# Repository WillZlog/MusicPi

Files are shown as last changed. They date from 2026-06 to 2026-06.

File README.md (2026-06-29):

# MusicPi







 


A server + remote that plays music so I don't have to be on my phone or on my computer to listen to music.

It controls playback with no phone, or computer necessary, so you can relax and listen to music **without the temptation of screens**. The case and PCB are all custom designed, by [@WillZlog](https://www.github.com/WillZlog).

## Tech Stack

**Remote:** ESP32 S3, buttons, OLED

**Receiver Dongle:** ESP32-C3 Super Mini, USB A - USB C Cable

**Raspberry Pi:** Python, Serial Listener, Librespot/Spotify

**CAD:** Onshape, custom enclosure

## Features

**Radio Mode:** Streams songs directly from commercial-free internet radio stations like FIP (France Inter Paris) or TSF (Télégraphie Sans Fil), to give you the classic radio style

**Physical Remote:** A physical remote with a (soon toggleable) OLED screen, and buttons, for full control of your music

**Raspberry Pi Music Server:** A Raspberry Pi streaming the music directly to speakers, no phone necessary!

**Spotify Integration:** Connects seamlessly directly with Spotify, and shows up as a speaker in the devices section

**OLED Screen:** Toggleable OLED screen that allows for quick checking of what song is playing, or which radio station is on!

**Uninterrupted listening:** ESP-NOW and unicast create a delayless connection between dongle and remote!

**Headless Setup:** Runs headlessly after setup, with no monitor or keyboard required.

**Custom PCB and custom case:** Every part, from the PCB to the case, was designed by yours truly, millimeter by millimeter, ensuring an accurate fit!

## How It Works

1. User presses a button on the remote
2. The remote sends a plain-text ESP-NOW command to the ESP32-C3 receiver dongle
3. Data gets transferred from ESP32-C3 to Raspberry Pi via serial USB connection (could be wireless)
4. Python script, `music_controller.py`, reads the command and then through librespot controls playback accordingly
5. Music gets streamed through Bluetooth to connected speakers

## Roadmap

- Battery for the remote so it doesn't have to be constantly plugged in

- Deep Sleep to save battery life

- Smaller enclosure design

## Controls
- Next x3 opens service menu
- Prev x3 toggles screen
- Play/pause x3 toggles radio mode

## Media

### Remote Prototype
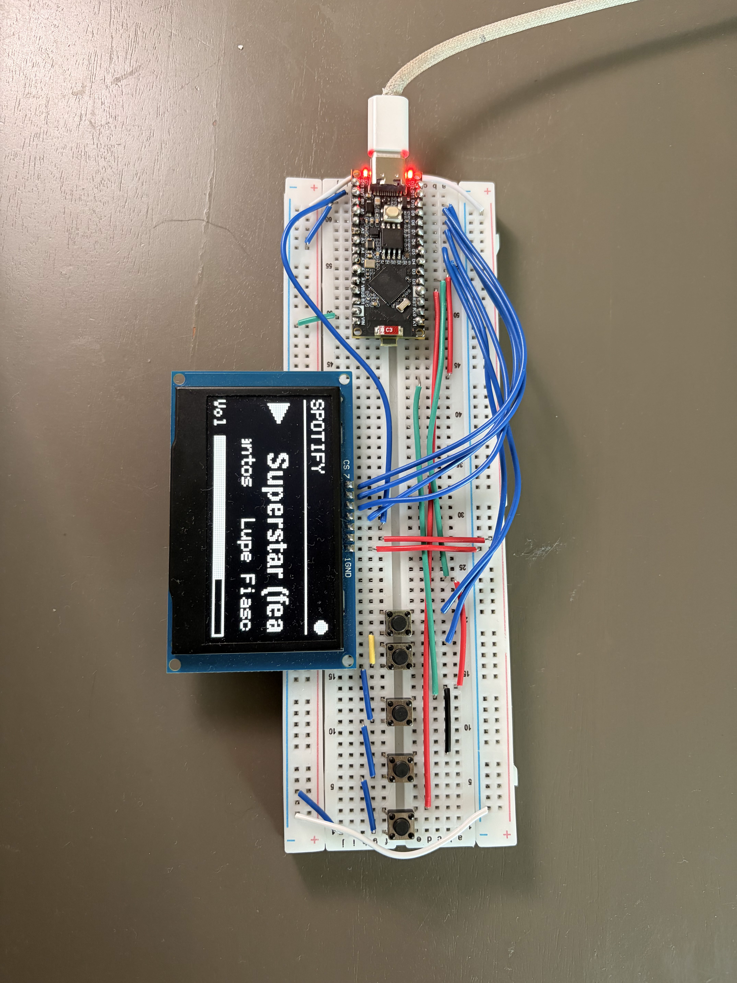
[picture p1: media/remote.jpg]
MusicPi remote


### CAD Designs
<p>
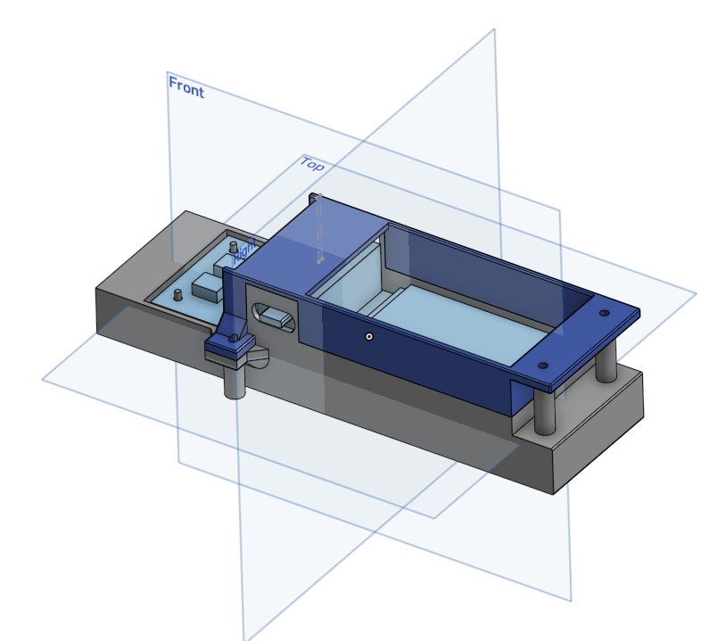
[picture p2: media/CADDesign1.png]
MusicPi CAD enclosure front view
  
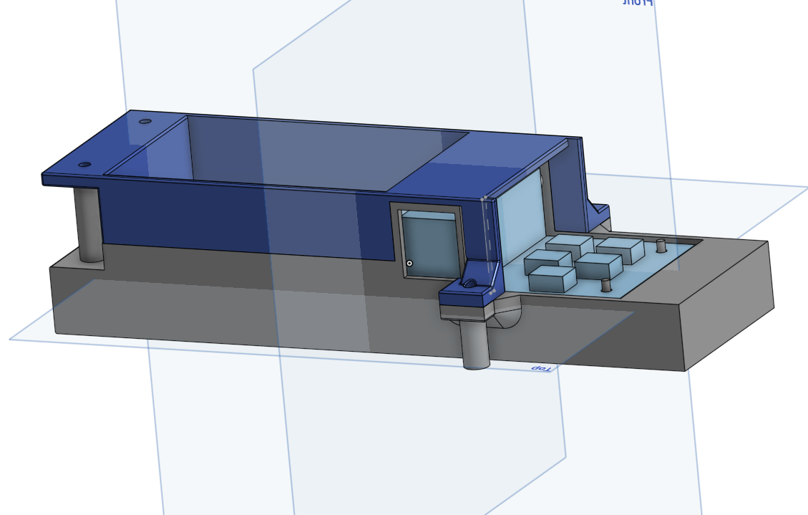
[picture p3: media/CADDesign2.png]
MusicPi CAD enclosure back view
  
</p>

### PCB and Schematic
<p>
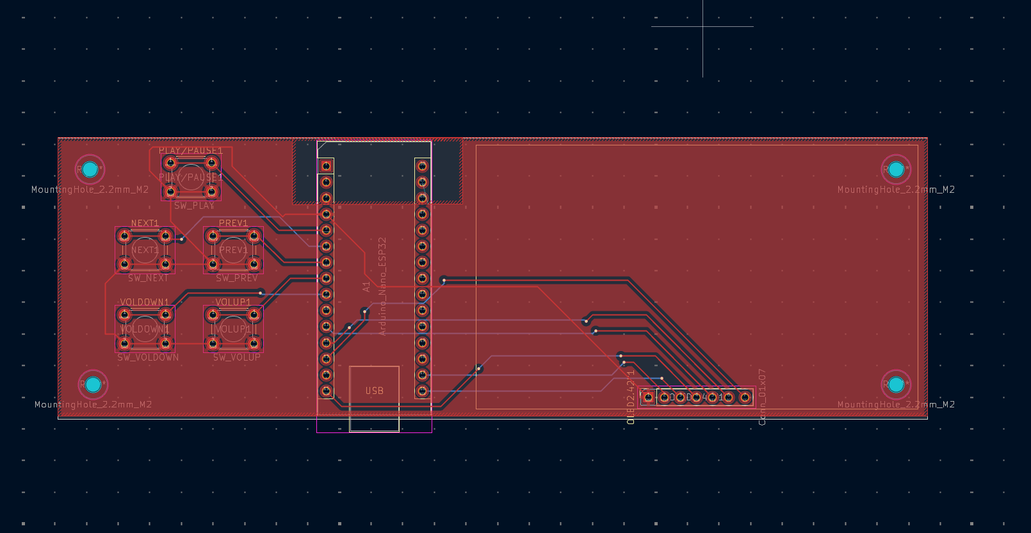
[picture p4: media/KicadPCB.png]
MusicPi KiCAD PCB screenshot
  
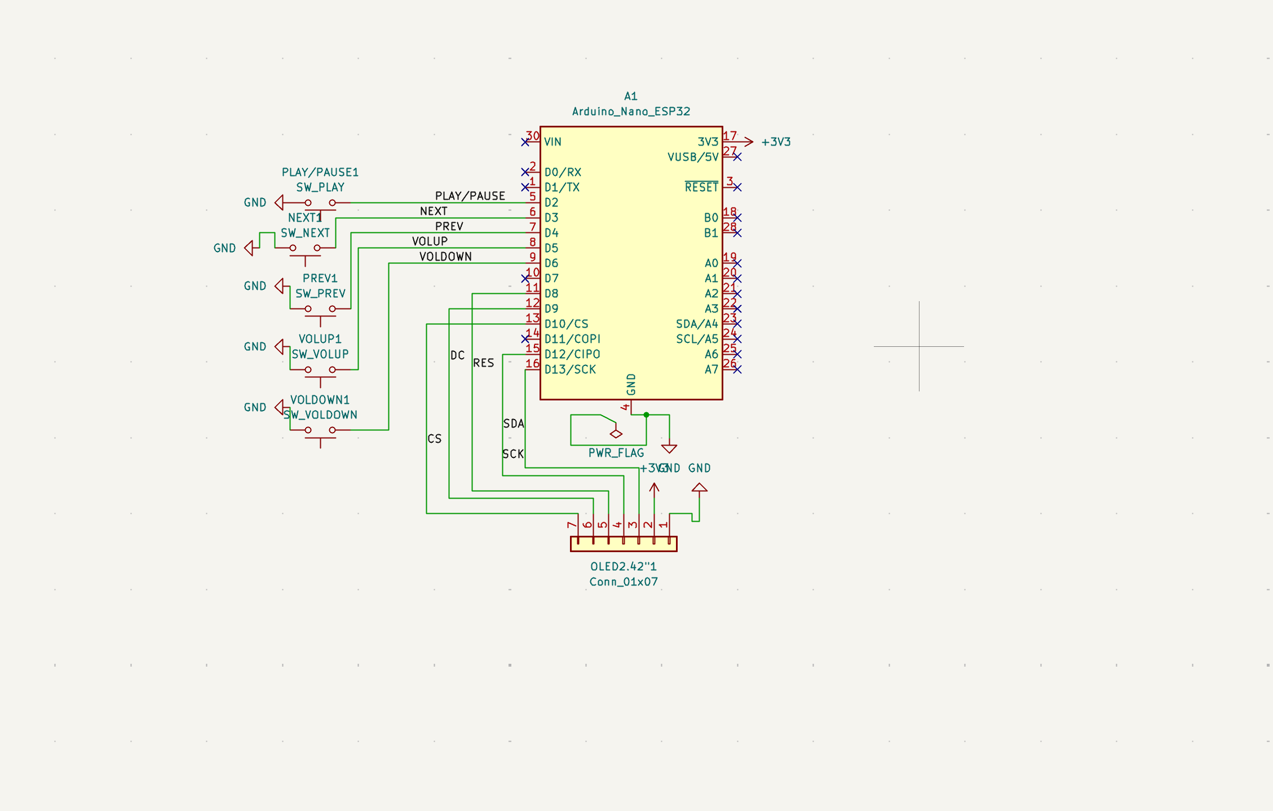
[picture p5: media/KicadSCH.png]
  
</p>

## Current Status

* Working
  * Pi server
  * Remote communication with server
  * OLED
  * Toggleable OLED
* Designed
  * Case
  * PCB
* In Progress
  * Better case design
* Planned
  * Battery system
  * Deep Sleep

## Authors

- [@WillZlog](https://www.github.com/WillZlog)

## License

This project is licensed under the MIT License.

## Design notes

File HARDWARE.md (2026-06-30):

# Hardware Specification: ESP32-C3, ESP32-S3, and Raspberry Pi

## 1. System Architecture Overview
The ESP32-S3 communicates with tthe ESP32-C3 over ESP-NOW, using ESP-NOW channel 1. The recieved data from the ESP32-C3 gets sent via serial to the Raspberry Pi

* **Communication Bus:** ESP-NOW
* **Primary Host:** Raspberry Pi 5
* **Remote Controller:** ESP32-S3
* **Receiver Dongle:** ESP32-C3 Super Mini
* **Display:** 2.42" SSD1309 128x64 OLED
* **Display Interface:** 4-wire SPI
* **Button Behavior:** Buttons are wired between the GPIO pin and GND. The firmware uses `INPUT_PULLUP`, so an unpressed button reads `HIGH` and a pressed button reads `LOW`.

---

## 2. Pinout Mappings and Wiring

### ESP32-S3 wiring

| Signal | ESP32 Pin | Connection |
| :--- | :---: | :--- |
| GND | GND | GND |
| 3.3V | 3.3V | OLED |
| Play/Pause | D2 | Switch |
| Next | D3 | Switch |
| Previous | D4 | Switch |
| Volume + | D5 | Switch |
| Volume - | D6 | Switch |
| SCK | D13 | OLED |
| SDA | D11 | OLED |
| RES | D8 | OLED |
| DC | D9 | OLED |
| CS | D10 | OLED |

---

## 3. Power Requirements and Electrical Specs

> [!NOTE]
> As of v1.0.0, both ESP32 boards and the Raspberry Pi are powered over USB-C.

* **GPIO Logic Level:** 3.3V
* **OLED Supply:** 3.3V from ESP32-S3
* **Button Inputs:** Active-low using internal pull-up resistors

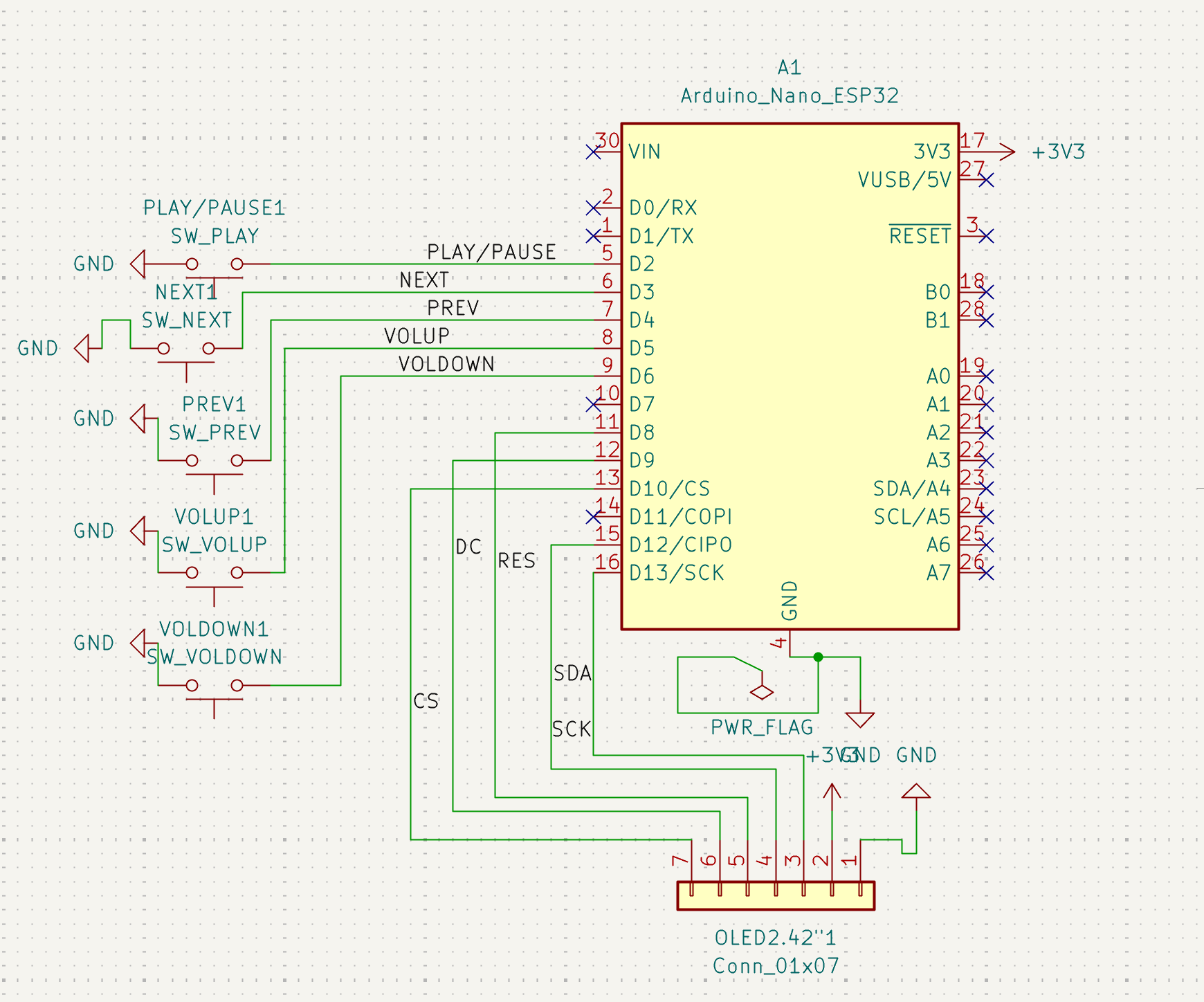
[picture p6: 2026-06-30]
kicad/schematic.png

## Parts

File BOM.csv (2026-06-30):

part | cost | link | quantity
2.42" SSD1309 128x64 OLED | $17 | https://www.amazon.com/HiLetgo-SSD1309-128x64-Display-Optional/dp/B0CFF46319?th=1 | 1
Raspberry Pi 5 | $350 | https://www.adafruit.com/product/6125?src=raspberrypi | 1
ESP32-C3 Super mini | $4 | https://www.amazon.com/ESP32-C3-Development-Bluetooth-Single-Core-Processor/dp/B0D4QK5V74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 | 1
ESP32-S3 | $14 | https://www.amazon.com/gp/product/B0D2DJTHPZ/ref=ox_sc_saved_image_3?smid=A3B0XDFTVR980O&psc=1 | 1
Tact switches | $5 | https://www.amazon.com/dp/B07X8T9D2Q/?coliid=I3G2GTZ4PO5O2F&colid=2NTMSQX9LIZRL | 5

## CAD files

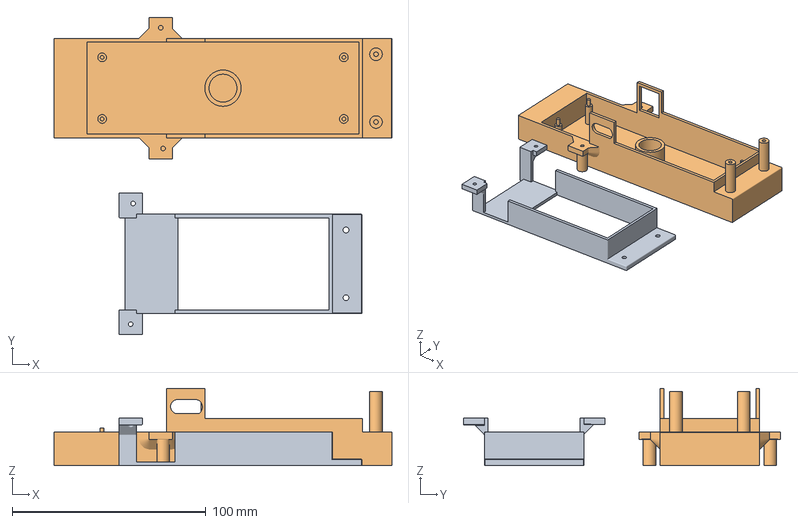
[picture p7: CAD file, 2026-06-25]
3Dprint_files/3MF/TopAndBottomCaseMusicPi.3mf
174.5 x 163.8 x 40.0 mm

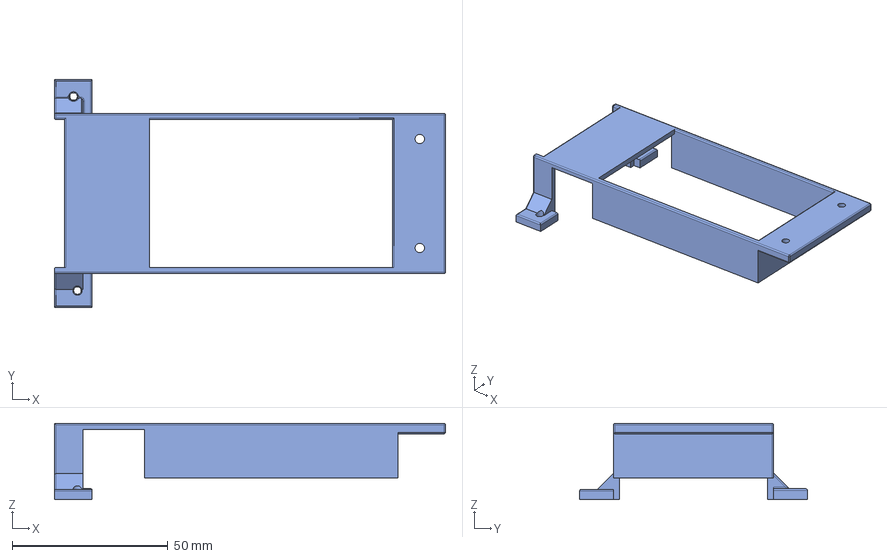
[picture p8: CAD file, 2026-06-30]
3Dprint_files/STEP/TopCase.step
125.5 x 73.1 x 24.5 mm

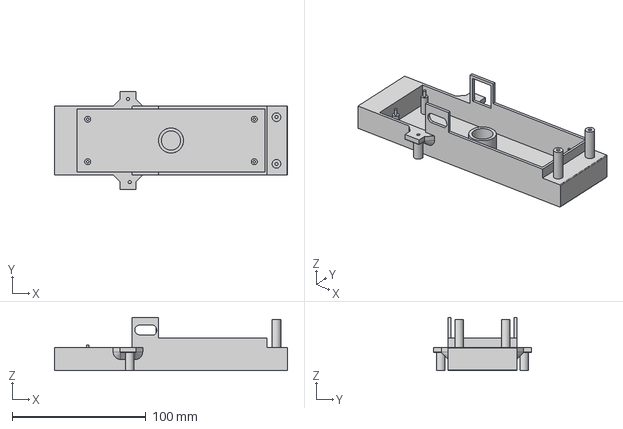
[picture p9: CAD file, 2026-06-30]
3Dprint_files/STEP/BottomCase.step
174.5 x 73.1 x 40.0 mm

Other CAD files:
3Dprint_files/STL/BottomCase.stl
3Dprint_files/STL/TopCase.stl

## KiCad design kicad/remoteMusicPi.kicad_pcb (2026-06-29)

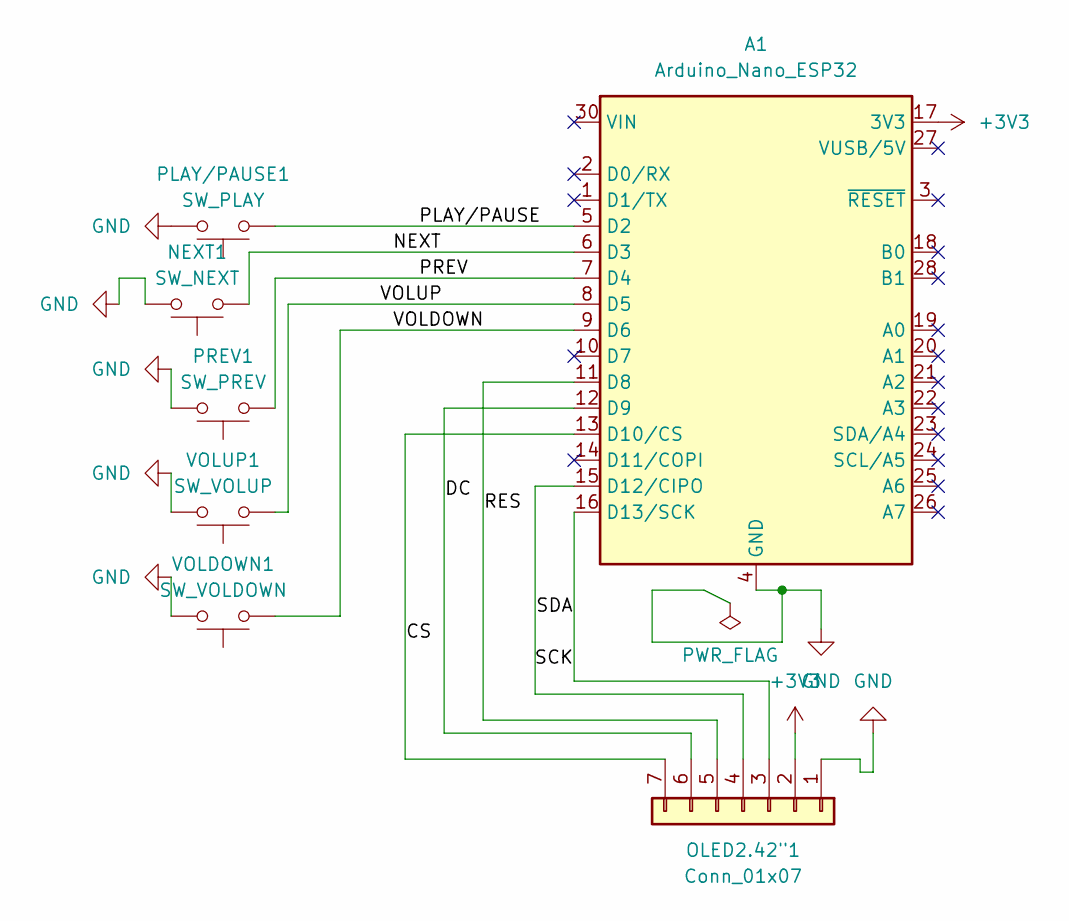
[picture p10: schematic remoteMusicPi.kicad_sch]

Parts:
A1: Arduino_Nano_ESP32; Arduino_Nano
NEXT1: SW_NEXT; SW_PUSH_6mm_H4.3mm
OLED2.42"1: Conn_01x07; PinSocket_1x07_P2.54mm_Vertical
PLAY/PAUSE1: SW_PLAY; SW_PUSH_6mm_H4.3mm
PREV1: SW_PREV; SW_PUSH_6mm_H4.3mm
VOLDOWN1: SW_VOLDOWN; SW_PUSH_6mm_H4.3mm
VOLUP1: SW_VOLUP; SW_PUSH_6mm_H4.3mm

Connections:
+3V3: A1.17 (3V3), OLED2.42"1.2
/CS: A1.13 (D10/CS), OLED2.42"1.7
/DC: A1.12 (D9), OLED2.42"1.6
/NEXT: A1.6 (D3), NEXT1.1
/PLAY/PAUSE: A1.5 (D2), PLAY/PAUSE1.1
/PREV: A1.7 (D4), PREV1.1
/RES: A1.11 (D8), OLED2.42"1.5
/SCK: A1.16 (D13/SCK), OLED2.42"1.3
/SDA: A1.15 (D12/CIPO), OLED2.42"1.4
/VOLDOWN: A1.9 (D6), VOLDOWN1.1
/VOLUP: A1.8 (D5), VOLUP1.1
GND: A1.4 (GND), A1.29 (GND), NEXT1.2, OLED2.42"1.1, PLAY/PAUSE1.2, PREV1.2, VOLDOWN1.2, VOLUP1.2

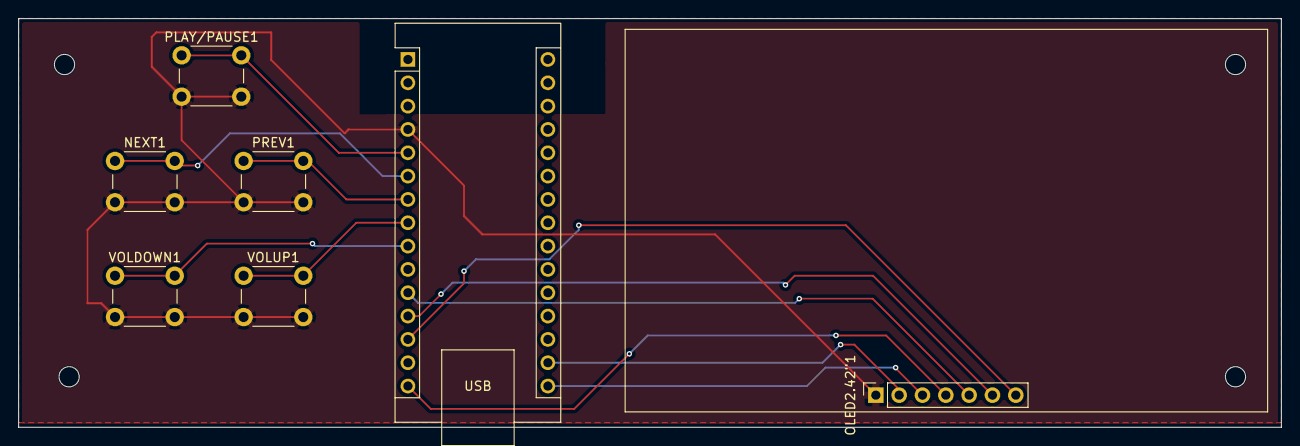
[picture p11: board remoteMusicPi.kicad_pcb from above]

Board: 2 copper layers, 137.5 x 44.5 mm, 7 parts (0 on the bottom side), 12 nets.

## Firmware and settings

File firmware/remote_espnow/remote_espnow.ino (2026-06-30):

// TODO: add deep-sleep-on-idle + button wake for battery life.

#include <U8g2lib.h>
#include <SPI.h>
#include <WiFi.h>
#include <esp_now.h>
#include <esp_wifi.h>
#include <math.h>


#define ESPNOW_CHANNEL 1
#define MUSICPI_VERSION "1.0.0"



// ---- OLED: 2.42" SSD1309 128x64, 4-wire SPI 9(Change for wtv screen you are running, this is the one I had)
U8G2_SSD1309_128X64_NONAME0_F_4W_SW_SPI u8g2(U8G2_R0, D13, D11, D10, D9, D8);




// ---------STRUCTS---------
struct Button
{
  uint8_t pin;
  const char *cmd;
  bool last;
  uint32_t tLast;
};

struct Service
{
  const char *label;
  const char *cmd;
  bool destructive;
};
// ---------------------------


// ----------CONSTANT VARIABLES------------
Button buttons[] = {
    {D2, "PLAY_PAUSE", HIGH, 0},
    {D3, "NEXT", HIGH, 0},
    {D4, "PREV", HIGH, 0},
    {D5, "VOL_UP", HIGH, 0},
    {D6, "VOL_DOWN", HIGH, 0},
    {D7, "BT_CONNECT", HIGH, 0},
};

const int NUM_BUTTONS = sizeof(buttons) / sizeof(buttons[0]);
const uint32_t DEBOUNCE_MS = 40;

//next conts
const uint32_t NEXT_WINDOW_MS = 500;
const int NEXT_TRIPLE = 3;

// prev consts
const uint32_t PREV_WINDOW_MS = 500;
const int PREV_TRIPLE = 3;

// service menu consts
const Service SERVICES[] = {
    {"Reconnect BT", "SVC_BT", false},
    {"Toggle Screen turn off", "SAO", false},
    {"Restart Spotify", "SVC_SPOTIFY", false},
    {"Restart Radio", "SVC_RADIO", false},
    {"Bounce Wi-Fi", "SVC_WIFI", false},
    {"Shutdown", "SVC_SHUTDOWN", true},
    {"Reboot", "SVC_REBOOT", true},
};
const int NUM_SERVICES = sizeof(SERVICES) / sizeof(SERVICES[0]);

// display consts
const int MENU_VISIBLE = 4;         // rows that fit under the header
const uint32_t MENU_TIMEOUT = 8000; // ms of inactivity before auto-close
const int TEXT_W = 104;       // px available for title / artist
const uint32_t FRAME_MS = 40; // animation step (marquee + intros)

// display/intro consts
const uint32_t INTRO_MS = 2000; // how long the intro plays
const uint32_t DISPLAY_TIMEOUT = 15000;

// esp32 communication consts
const uint32_t HELLO_INTERVAL = 3000; // ms between HELLO keepalives
const uint32_t STALE_MS = 6000; // no status for this long -> "offline"
// ---------------------------


// ---------ENUMS-----------

enum UiMode
{
  UI_NOWPLAYING,
  UI_MENU,
  UI_CONFIRM,
  UI_INTRO,
  UI_STARTUP
};

enum Theme
{
  TH_JAZZ,
  TH_ROCK,
  TH_ELECTRO,
  TH_GROOVE,
  TH_REGGAE,
  TH_WORLD,
  TH_DEFAULT
};
// ---------------------------




//-------GLOBAL VARIABLES----------
uint32_t lastButtonPress;

//next vars
int nextCount = 0;
uint32_t nextDeadline = 0;

//prev vars
int prevCount = 0;
uint32_t prevDeadline = 0;

// service menu 
UiMode ui = UI_NOWPLAYING;
int menuSel = 0;                    // highlighted service
int menuTop = 0;                    // first visible row (scroll offset)
uint32_t menuDeadline = 0;          // auto-close time

// dongle <-> remote communication variables
static uint8_t dongle_mac[6];
static bool have_dongle = false;
static uint8_t rxSrc[6];              // sender MAC of the last frame
uint32_t lastHelloMs = 0;
uint32_t lastStatusMs = 0;      // 0 = never heard from the Pi
bool wasOnline = false;
static uint8_t BROADCAST[6] = {0xFF, 0xFF, 0xFF, 0xFF, 0xFF, 0xFF};
static volatile bool rxReady = false;
static char rxData[210];
static volatile size_t rxLen = 0;

// display 
uint32_t lastFrameMs = 0;
int scroll1 = 0, scroll2 = 0;            // marquee offsets for title / artist
bool scrolling = false;                  // any line currently overflowing?
String shownLine1 = "", shownLine2 = ""; // text the marquee is tracking
bool displayOn = true;
bool displayHidden = false;
bool displayAlwaysOn = false;
bool startupDone = false;


// theme and animation playing for radio stations
Theme introTheme = TH_DEFAULT;
uint32_t introStart = 0;
String lastRadioStation = "";   // last station we animated for

//status received from the Pi
String mode = "SPOTIFY", state = "PAUSED", line1 = "", line2 = "", vol = "?";
bool dirty = true;
// ---------------------------





// compatibale with both versions of esp arduino versions
// if statement creates correct onRecv() for version
//* both versions define src, src = MAC address of the device that sent ESP-NOW
// MAC Address is 6 bytes, 6 bytes are saved to rxSRC
#if ESP_ARDUINO_VERSION >= ESP_ARDUINO_VERSION_VAL(3, 0, 0)
void onRecv(const esp_now_recv_info_t *info, const uint8_t *data, int len)
{
  const uint8_t *src = info->src_addr;
#else
void onRecv(const uint8_t *mac, const uint8_t *data, int len)
{
  const uint8_t *src = mac;
#endif
  memcpy(rxSrc, src, 6);

  // checks if there is already an unread message, if so then ignore the one just recieved 
  if (rxReady)
    return;

  // stores data inside rxData safely
  size_t n = (len < (int)sizeof(rxData) - 1) ? len : sizeof(rxData) - 1;
  memcpy(rxData, data, n);
  rxData[n] = '\0';

  // store length of message and say that it is ready to recieve new message
  rxLen = n;
  rxReady = true;
}

// sends a cmd over espnow using built in function: esp_now_send()
// sends to everyone if doesn't know dongle MAC Address
void sendCmd(const char *cmd)
{
  const uint8_t *dst = have_dongle ? dongle_mac : BROADCAST;
  esp_now_send(dst, (const uint8_t *)cmd, strlen(cmd));
}

//starts up the remote
//serial port at 115200 baud
//sets buttons as input pullup
//puts esp32 in station mode for espnow
//sets espnow channel, 1
void setup()
{
  Serial.begin(115200);
  for (int i = 0; i < NUM_BUTTONS; i++)
    pinMode(buttons[i].pin, INPUT_PULLUP);

  // ESP-NOW radio
  WiFi.mode(WIFI_STA);
  WiFi.disconnect();
  esp_wifi_set_channel(ESPNOW_CHANNEL, WIFI_SECOND_CHAN_NONE);
  esp_wifi_set_ps(WIFI_PS_NONE); //* disables wifi power saving, this is optional, makes the signal more reliable and faster but also eats more power, if using battery turn this on, but for now its fine
  if (esp_now_init() != ESP_OK)
  {
    Serial.println("esp_now_init failed");
  }
  esp_now_register_recv_cb(onRecv); // on recieve message run onRecv()
  
  // sets up broadcast peer, adds the broadcast address as an espnow peer, [0xFF, 0xFF...]
  esp_now_peer_info_t peer = {};
  memcpy(peer.peer_addr, BROADCAST, 6);
  peer.channel = ESPNOW_CHANNEL;
  peer.encrypt = false;
  esp_now_add_peer(&peer);

  //starts up the oled
  u8g2.begin();
  u8g2.setBusClock(2000000);
  drawScreen();
}



void loop()
{
  readButtons();
  uint32_t now = millis(); // async delay()s basically along with below code

  if (!startupDone)
    if (now < 3000)
    {
      ui = UI_STARTUP;
      drawScreen();
      return;
    }
    else 
    {
      startupDone = true;
      ui=UI_NOWPLAYING;
      dirty = true;
    }

  if (nextDeadline && now >= nextDeadline)
    flushNext();
  if (prevDeadline && now >= prevDeadline)
    flushPrev();

  // autoclose service window
  if (ui != UI_NOWPLAYING && menuDeadline && now >= menuDeadline)
    closeMenu();

  // hello unicast
  if (now - lastHelloMs >= HELLO_INTERVAL)
  {
    sendCmd("HELLO");
    lastHelloMs = now;
  }

  if (rxReady)
  {
    String s = String(rxData);
    if (s.startsWith("ST|"))
    { // only trust real status frames
      if (!have_dongle)
        learnDongle();
      parseStatus(s);
      lastStatusMs = now;
      recomputeScroll();

      if (mode == "RADIO" && line1 != lastRadioStation)
      {
        lastRadioStation = line1;
        if (ui == UI_NOWPLAYING || ui == UI_INTRO)
        {
          introTheme = themeFor(line1);
          introStart = now;
          ui = UI_INTRO;
        }
      }
      else if (mode != "RADIO")
      {
        lastRadioStation = "";
      }
    }
    rxReady = false;
  }

  bool animating = (ui == UI_INTRO) || (ui == UI_NOWPLAYING && scrolling);
  if (animating && now - lastFrameMs >= FRAME_MS)
  {
    lastFrameMs = now;
    if (ui == UI_NOWPLAYING)
    {
      scroll1++;
      scroll2++;
    }
    dirty = true;
  }
  if (ui == UI_INTRO && now - introStart >= INTRO_MS)
  {
    ui = UI_NOWPLAYING;
    dirty = true;
  }

  bool on = isOnline();
  if (on != wasOnline)
  {
    wasOnline = on;
    dirty = true;
  }

  if (dirty)
  {
    drawScreen();
    dirty = false;
  }

  if (now-lastButtonPress > DISPLAY_TIMEOUT)
  {
    if (!displayAlwaysOn)
    {
      displayHidden = true;
      displayOn = false;
      u8g2.setPowerSave(1);
    }
  }
  else
  {
    if (displayHidden){
      displayHidden = false;
      displayOn = true;
      u8g2.setPowerSave(0);
      dirty = true;
    }
  }
}

void learnDongle()
{
  memcpy(dongle_mac, rxSrc, 6);
  esp_now_peer_info_t peer = {};
  memcpy(peer.peer_addr, dongle_mac, 6);
  peer.channel = ESPNOW_CHANNEL;
  peer.encrypt = false;
  esp_now_add_peer(&peer);
  have_dongle = true;
}

bool isOnline()
{
  return lastStatusMs != 0 && (millis() - lastStatusMs) < STALE_MS;
}

void readButtons()
{
  uint32_t now = millis();
  for (int i = 0; i < NUM_BUTTONS; i++)
  {
    bool s = digitalRead(buttons[i].pin);
    if (s != buttons[i].last && (now - buttons[i].tLast) > DEBOUNCE_MS)
    {
      buttons[i].tLast = now;
      if (s == LOW)
        handlePress(buttons[i].cmd); // pressed
      buttons[i].last = s;
    }
  }
}

void flushNext()
{
  for (int i = 0; i < nextCount; i++)
  {
    sendCmd("NEXT");
    delay(10); // small gap so back-to-back sends don't drop
  }
  nextCount = 0;
  nextDeadline = 0;
}

void toggleDisplay()
{
  displayOn = !displayOn;

  if (displayOn)
  {
    u8g2.setPowerSave(0); // wake OLED
    dirty = true;
  }
  else
  {
    u8g2.clearBuffer();
    u8g2.sendBuffer();
    u8g2.setPowerSave(1); // sleep OLED
  }
}

void flushPrev()
{
  for (int i = 0; i < prevCount; i++)
  {
    sendCmd("PREV");
    delay(10);
  }
  prevCount = 0;
  prevDeadline = 0;
}

void openMenu()
{
  ui = UI_MENU;
  menuSel = 0;
  menuTop = 0;
  menuDeadline = millis() + MENU_TIMEOUT;
  dirty = true;
}

void closeMenu()
{
  ui = UI_NOWPLAYING;
  menuDeadline = 0;
  dirty = true; // redraw the now-playing screen
}

void adjustScroll()
{
  if (menuSel < menuTop)
    menuTop = menuSel;
  if (menuSel >= menuTop + MENU_VISIBLE)
    menuTop = menuSel - MENU_VISIBLE + 1;
}

void handlePress(const char *cmd)
{
  uint32_t now = millis();

  lastButtonPress = now;

  if (displayHidden)
  {
    return;
  }
  if (ui == UI_INTRO)
    ui = UI_NOWPLAYING; // any press dismisses the intro

  if (ui == UI_NOWPLAYING)
  {
    if (strcmp(cmd, "NEXT") == 0)
    {
      flushPrev();

      nextCount++;
      nextDeadline = now + NEXT_WINDOW_MS;

      if (nextCount >= NEXT_TRIPLE)
      { // triple-click NEXT -> menu, send no skips
        nextCount = 0;
        nextDeadline = 0;
        openMenu();
      }
      return;
    }

    if (strcmp(cmd, "PREV") == 0)
    {
      flushNext();

      prevCount++;
      prevDeadline = now + PREV_WINDOW_MS;

      if (prevCount >= PREV_TRIPLE)
      { // triple-click PREV -> display toggle
        prevCount = 0;
        prevDeadline = 0;
        toggleDisplay();
      }
      return;
    }

    flushNext();
    flushPrev();

    // when display is off, any normal button can still send commands
    sendCmd(cmd);
    return;
  }

  menuDeadline = now + MENU_TIMEOUT;

  if (ui == UI_MENU)
  {
    if (strcmp(cmd, "NEXT") == 0)
    {
      menuSel = (menuSel + 1) % NUM_SERVICES;
      adjustScroll();
      dirty = true;
    }
    else if (strcmp(cmd, "PREV") == 0)
    {
      menuSel = (menuSel - 1 + NUM_SERVICES) % NUM_SERVICES;
      adjustScroll();
      dirty = true;
    }
    else if (strcmp(cmd, "PLAY_PAUSE") == 0)
    {
      if (SERVICES[menuSel].cmd == "SAO")
      {
        displayAlwaysOn = !displayAlwaysOn;
      }
      else if (SERVICES[menuSel].destructive)
      {
        ui = UI_CONFIRM;
        dirty = true;
      }
      else
      {
        sendCmd(SERVICES[menuSel].cmd);
        closeMenu();
      }
    }
    else if (strcmp(cmd, "BT_CONNECT") == 0)
    {
      closeMenu(); // cancel, howeverr bt_connect button doesnt exist, so just here for future implementation
    }

    return;
  }

  if (ui == UI_CONFIRM)
  {
    if (strcmp(cmd, "PLAY_PAUSE") == 0)
    {
      sendCmd(SERVICES[menuSel].cmd);
      closeMenu();
    }
    else
    {
      ui = UI_MENU; // any other button backs out
      dirty = true;
    }
    return;
  }
}

void parseStatus(String s)
{
  if (!s.startsWith("ST|"))
    return;
  String f[6];
  int n = 0, start = 0;
  for (int i = 0; i < (int)s.length() && n < 6; i++)
  {
    if (s[i] == '|')
    {
      f[n++] = s.substring(start, i);
      start = i + 1;
    }
  }
  if (n < 6)
    f[n++] = s.substring(start);

  mode = f[1];
  state = f[2];
  line1 = f[3];
  line2 = f[4];
  vol = f[5];
  dirty = true;
}

void recomputeScroll()
{
  if (line1 != shownLine1)
  {
    scroll1 = 0;
    shownLine1 = line1;
  }
  if (line2 != shownLine2)
  {
    scroll2 = 0;
    shownLine2 = line2;
  }
  u8g2.setFont(u8g2_font_helvB10_tf);
  bool s1 = u8g2.getStrWidth(line1.c_str()) > TEXT_W;
  u8g2.setFont(u8g2_font_6x12_tf);
  bool s2 = u8g2.getStrWidth(line2.c_str()) > TEXT_W;
  scrolling = s1 || s2;
}

void drawScrolling(int x, int y, const String &s, int maxPx, int offset)
{
  int w = u8g2.getStrWidth(s.c_str());
  if (w <= maxPx)
  {
    u8g2.drawStr(x, y, s.c_str());
    return;
  }
  const int gap = 18;
  int period = w + gap;
  int o = offset % period;
  u8g2.setClipWindow(x, 0, x + maxPx, 63);
  u8g2.drawStr(x - o, y, s.c_str());
  u8g2.drawStr(x - o + period, y, s.c_str());
  u8g2.setMaxClipWindow();
}

int parseVol(const String &v)
{
  if (v.length() == 0 || v == "?")
    return -1;
  int n = v.toInt();
  return n < 0 ? 0 : (n > 100 ? 100 : n);
}

void drawScreen()
{
  if (!startupDone){
    drawStartup();
    return;
  }

  if (!displayOn || displayHidden)
    return;

  switch (ui)
  {
  case UI_MENU:
    drawMenu();
    break;
  case UI_CONFIRM:
    drawConfirm();
    break;
  case UI_INTRO:
    drawIntro();
    break;
  case UI_STARTUP:
    drawStartup();
  default:
    drawNowPlaying();
  }
}

void drawStartup()
{
  String stringInput = "Version " + String(MUSICPI_VERSION);
  u8g2.clearBuffer();
  u8g2.setFont(u8g2_font_profont12_mf);
  u8g2.drawStr(0, 20, "MusicPi");
  u8g2.drawStr(0,40,stringInput.c_str());
  u8g2.sendBuffer();
}

void drawMenu()
{
  u8g2.clearBuffer();
  u8g2.setFont(u8g2_font_6x12_tf);
  u8g2.drawStr(0, 10, "SERVICE MENU");
  u8g2.drawHLine(0, 13, 128);

  for (int row = 0; row < MENU_VISIBLE; row++)
  {
    int idx = menuTop + row;
    if (idx >= NUM_SERVICES)
      break;
    int y = 25 + row * 12; // 25, 37, 49, 61
    if (idx == menuSel)
      u8g2.drawStr(0, y, ">");
    u8g2.drawStr(10, y, SERVICES[idx].label);
  }

  // scroll hints on the right edge
  if (menuTop > 0)
    u8g2.drawStr(122, 25, "^");
  if (menuTop + MENU_VISIBLE < NUM_SERVICES)
    u8g2.drawStr(122, 61, "v");

  u8g2.sendBuffer();
}

void drawConfirm()
{
  u8g2.clearBuffer();
  u8g2.setFont(u8g2_font_6x12_tf);
  u8g2.drawStr(0, 10, "CONFIRM");
  u8g2.drawHLine(0, 13, 128);
  u8g2.drawStr(0, 32, SERVICES[menuSel].label);
  u8g2.drawStr(0, 48, "PLAY = confirm");
  u8g2.drawStr(0, 60, "any other cancels");
  u8g2.sendBuffer();
}

void drawNowPlaying()
{
  u8g2.clearBuffer();
  bool online = isOnline();

  // top bar: mode (left), link indicator (right)
  u8g2.setFont(u8g2_font_6x12_tf);
  u8g2.drawStr(0, 10, mode.c_str());
  if (online)
    u8g2.drawDisc(124, 5, 3); // filled = link up
  else
    u8g2.drawCircle(124, 5, 3); // hollow = stale / no link
  u8g2.drawHLine(0, 13, 128);

  if (lastStatusMs == 0)
  {
    const char *w = "Waiting for Pi...";
    u8g2.drawStr((128 - u8g2.getStrWidth(w)) / 2, 40, w);
    u8g2.sendBuffer();
    return;
  }

  // play/pause indicator
  bool playing = (state == "PLAYING");
  u8g2.setFont(u8g2_font_open_iconic_play_2x_t);
  u8g2.drawGlyph(0, 36, playing ? 0x45 : 0x44); // play / pause icon

  // title (line1) + subtitle (line2), scrolling if too long to fit
  u8g2.setFont(u8g2_font_helvB10_tf);
  drawScrolling(22, 34, line1, TEXT_W, scroll1);
  u8g2.setFont(u8g2_font_6x12_tf);
  drawScrolling(22, 48, line2, TEXT_W, scroll2);

  // volume bar along the bottom
  int vpct = parseVol(vol);
  u8g2.setFont(u8g2_font_5x7_tf);
  u8g2.drawStr(0, 63, "Vol");
  const int bx = 20, bw = 108; // bar spans x = 20..128
  u8g2.drawFrame(bx, 57, bw, 6);
  if (vpct >= 0)
    u8g2.drawBox(bx + 1, 58, (bw - 2) * vpct / 100, 4);

  u8g2.sendBuffer();
}

// ---- station intro animations ----------------------------------------------

Theme themeFor(String name)
{
  name.toLowerCase();
  if (name.indexOf("jazz") >= 0)
    return TH_JAZZ;
  if (name.indexOf("rock") >= 0 || name.indexOf("metal") >= 0)
    return TH_ROCK;
  if (name.indexOf("electro") >= 0)
    return TH_ELECTRO;
  if (name.indexOf("groove") >= 0)
    return TH_GROOVE;
  if (name.indexOf("reggae") >= 0)
    return TH_REGGAE;
  if (name.indexOf("monde") >= 0 || name.indexOf("world") >= 0)
    return TH_WORLD;
  return TH_DEFAULT;
}

// music note for jazz and stuff
void drawNote(int x, int y)
{
  u8g2.drawDisc(x, y, 2);
  u8g2.drawVLine(x + 2, y - 9, 9);
  u8g2.drawHLine(x + 2, y - 9, 3);
}

void animBars(uint32_t t, int n, float speed, float spread, int maxh)
{
  int slot = 128 / n;
  for (int i = 0; i < n; i++)
  {
    float p = t / speed + i * spread;
    int h = 4 + (int)((sin(p) * 0.5 + 0.5) * maxh);
    u8g2.drawBox(i * slot + 2, 50 - h, slot - 4, h);
  }
}

void animRock(uint32_t t) { animBars(t, 14, 90.0, 1.7, 44); }
void animGroove(uint32_t t) { animBars(t, 8, 260.0, 0.7, 40); }
void animDefault(uint32_t t) { animBars(t, 10, 200.0, 0.6, 40); }

void animJazz(uint32_t t)
{
  float ph = t / 1000.0;
  for (int i = 0; i < 5; i++)
  {
    int x = 16 + i * 24 + (int)(5 * sin(ph * 2 + i));
    int y = 50 - ((int)(ph * 22 + i * 13) % 50);
    drawNote(x, y);
  }
}

void animElectro(uint32_t t)
{
  float ph = t / 140.0;
  int py = 28;
  for (int x = 0; x <= 128; x += 4)
  {
    int y = 28 + (int)(16 * sin(x / 11.0 + ph));
    if (x)
      u8g2.drawLine(x - 4, py, x, y);
    py = y;
  }
  u8g2.drawCircle(64, 28, (t / 45) % 26); // expanding pulse
}

void animReggae(uint32_t t)
{
  u8g2.drawBox(0, 0, 128, 5); // three bands (mono stand-in)
  u8g2.drawBox(0, 7, 128, 5);
  u8g2.drawBox(0, 14, 128, 5);
  int sy = 52 - (int)((t / 60) % 34); // rising sun
  u8g2.drawDisc(64, sy, 7);
  for (int a = 0; a < 360; a += 45)
  {
    float r = a * 0.0174533;
    u8g2.drawLine(64 + cos(r) * 9, sy + sin(r) * 9,
                  64 + cos(r) * 13, sy + sin(r) * 13);
  }
}

void animWorld(uint32_t t)
{
  int cx = 64, cy = 28, R = 20;
  u8g2.drawCircle(cx, cy, R);
  u8g2.drawHLine(cx - R, cy, 2 * R);
  u8g2.drawEllipse(cx, cy, R, R / 2);
  float ph = t / 350.0;
  for (int m = 0; m < 3; m++)
  { // meridians sweeping = spin
    int rx = (int)(R * fabs(sin(ph + m * 1.05)));
    if (rx > 0)
      u8g2.drawEllipse(cx, cy, rx, R);
  }
}

void drawIntro()
{
  uint32_t t = millis() - introStart;
  u8g2.clearBuffer();
  switch (introTheme)
  {
  case TH_JAZZ:
    animJazz(t);
    break;
  case TH_ROCK:
    animRock(t);
    break;
  case TH_ELECTRO:
    animElectro(t);
    break;
  case TH_GROOVE:
    animGroove(t);
    break;
  case TH_REGGAE:
    animReggae(t);
    break;
  case TH_WORLD:
    animWorld(t);
    break;
  default:
    animDefault(t);
  }
  // station name banner along the bottom
  u8g2.setFont(u8g2_font_6x12_tf);
  int nx = (128 - u8g2.getStrWidth(line1.c_str())) / 2;
  if (nx < 0)
    nx = 0;
  u8g2.drawStr(nx, 63, line1.c_str());
  u8g2.sendBuffer();
}

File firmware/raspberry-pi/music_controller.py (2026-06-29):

import serial
import subprocess
import time
import re

PORT = "/dev/ttyACM0" 
BAUD = 115200

SPEAKER_MAC = "41:42:E1:EE:2D:F4" #HARDCODED SPEAKER MAC ADDRESS, HAVE TO FIND THiS BEFORE PAIRING

PP_WINDOW = 0.8
TRIPLE_PRESS = 3

RADIO_STATIONS = [
    ("FIP",            "https://icecast.radiofrance.fr/fip-midfi.mp3"),
    ("FIP Rock",       "https://icecast.radiofrance.fr/fiprock-midfi.mp3"),
    ("FIP Jazz",       "https://icecast.radiofrance.fr/fipjazz-midfi.mp3"),
    ("FIP Groove",     "https://icecast.radiofrance.fr/fipgroove-midfi.mp3"),
    ("FIP Monde",      "https://icecast.radiofrance.fr/fipworld-midfi.mp3"),
    ("FIP Nouveautes", "https://icecast.radiofrance.fr/fipnouveautes-midfi.mp3"),
    ("FIP Reggae",     "https://icecast.radiofrance.fr/fipreggae-midfi.mp3"),
    ("FIP Electro",    "https://icecast.radiofrance.fr/fipelectro-midfi.mp3"),
    ("FIP Pop",        "https://icecast.radiofrance.fr/fippop-midfi.mp3"),
    ("FIP Metal",      "https://icecast.radiofrance.fr/fipmetal-midfi.mp3"),
    ("FIP Hip-Hop",    "https://icecast.radiofrance.fr/fiphiphop-midfi.mp3"),
    ("TSF Jazz",       "https://tsfjazz.ice.infomaniak.ch/tsfjazz-high.mp3"),
    ("SomaFM Groove Salad", "https://ice1.somafm.com/groovesalad-128-mp3"),
    ("SomaFM Lush",         "https://ice1.somafm.com/lush-128-mp3"),
    ("Radio Paradise Rock", "https://stream.radioparadise.com/rock-128"),
    ("Radio Paradise Jazz", "https://stream.radioparadise.com/jazz-128"),
]


VALID_COMMANDS = {
    "PLAY_PAUSE",
    "NEXT",
    "PREV",
    "VOL_UP",
    "VOL_DOWN",
    # Service menu (triggered by pressing NEXT 3 times in a row on the remote)
    "SVC_BT",        # disconnect + reconnect the Bluetooth speaker
    "SVC_SPOTIFY",   # restart the spotifyd user service
    "SVC_RADIO",     # restart the current radio stream
    "SVC_WIFI",      # bounce Wi-Fi
    "SVC_SHUTDOWN",  # safe power off
    "SVC_REBOOT",    # reboot
}

# ----- runtime state -----
radio_mode = False
radio_index = 0
radio_player = None       

pp_count = 0              
pp_deadline = 0.0     


def log(*args):
    print(*args, flush=True)


def run(command):
    return subprocess.run(
        command,
        stdout=subprocess.DEVNULL,
        stderr=subprocess.DEVNULL
    )


def connect_bluetooth_speaker():
    log(f"Trying to connect Bluetooth speaker: {SPEAKER_MAC}")

    run(["bluetoothctl", "power", "on"])
    run(["bluetoothctl", "trust", SPEAKER_MAC])

    result = subprocess.run(
        ["bluetoothctl", "connect", SPEAKER_MAC],
        capture_output=True,
        text=True
    )

    output = (result.stdout + result.stderr).lower()

    if "connection successful" in output or "already connected" in output:
        log("Bluetooth speaker connected.")
        return True

    log("Bluetooth connect output:")
    log(result.stdout.strip())
    log(result.stderr.strip())
    return False


def spotify_action(action):
    result = subprocess.run(
        ["playerctl", action],
        capture_output=True,
        text=True
    )
    if result.returncode != 0:
        log("playerctl error:", result.stderr.strip())


def radio_is_playing():
    return radio_player is not None and radio_player.poll() is None


def radio_stop():
    global radio_player
    if radio_is_playing():
        radio_player.terminate()
        try:
            radio_player.wait(timeout=2)
        except subprocess.TimeoutExpired:
            radio_player.kill()
    radio_player = None


def radio_start(index):
    global radio_player, radio_index
    radio_stop()
    radio_index = index % len(RADIO_STATIONS)
    name, url = RADIO_STATIONS[radio_index]
    log(f"Radio: playing {name} ({url})")
    radio_player = subprocess.Popen(
        ["mpv", "--no-video", "--really-quiet", url],
        stdout=subprocess.DEVNULL,
        stderr=subprocess.DEVNULL
    )


def radio_next():
    radio_start(radio_index + 1)


def radio_prev():
    radio_start(radio_index - 1)


def radio_play_pause():
    if radio_is_playing():
        log("Radio: stop")
        radio_stop()
    else:
        log("Radio: resume")
        radio_start(radio_index)


def toggle_radio_mode():
    global radio_mode
    if not radio_mode:
        log("Switching to RADIO mode")
        radio_mode = True
        spotify_action("pause")          # quiet Spotify before radio starts
        radio_start(radio_index)
    else:
        log("Switching to SPOTIFY mode")
        radio_mode = False
        radio_stop()
        spotify_action("play")           # resume Spotify playback


def register_play_pause():
    global pp_count, pp_deadline
    pp_count += 1
    pp_deadline = time.monotonic() + PP_WINDOW


def flush_play_pause():
    global pp_count, pp_deadline
    n = pp_count
    pp_count = 0
    pp_deadline = 0.0
    if n <= 0:
        return
    if n >= TRIPLE_PRESS:
        toggle_radio_mode()
    else:
        if radio_mode:
            radio_play_pause()
        else:
            spotify_action("play-pause")


# ----- Service menu actions -----
def svc_reconnect_bt():
    log("Service: reconnect Bluetooth speaker")
    run(["bluetoothctl", "disconnect", SPEAKER_MAC])
    time.sleep(2)
    connect_bluetooth_speaker()


def svc_restart_spotify():
    log("Service: restart spotifyd")
    run(["systemctl", "--user", "restart", "spotifyd"])


def svc_restart_radio():
    log("Service: restart radio stream")
    if radio_mode:
        radio_start(radio_index)        
    else:
        log("(not in radio mode; nothing to restart)")


def svc_restart_wifi():
    log("Service: bounce Wi-Fi")
    run(["nmcli", "radio", "wifi", "off"])
    time.sleep(2)
    run(["nmcli", "radio", "wifi", "on"])


def svc_power(action):
    log(f"Service: {action}")
    radio_stop()                      
    r = subprocess.run(
        ["sudo", "-n", "systemctl", action],
        capture_output=True, text=True
    )
    if r.returncode != 0:
        log(f"{action} failed (is the sudoers rule installed?):",
            r.stderr.strip())


def handle_command(line):
    flush_play_pause()

    if line == "NEXT":
        if radio_mode:
            radio_next()
        else:
            spotify_action("next")

    elif line == "PREV":
        if radio_mode:
            radio_prev()
        else:
            spotify_action("previous")

    elif line == "VOL_UP":
        run(["pactl", "set-sink-volume", "@DEFAULT_SINK@", "+5%"])

    elif line == "VOL_DOWN":
        run(["pactl", "set-sink-volume", "@DEFAULT_SINK@", "-5%"])

    elif line == "BT_CONNECT":
        connect_bluetooth_speaker()

    elif line == "SVC_BT":
        svc_reconnect_bt()

    elif line == "SVC_SPOTIFY":
        svc_restart_spotify()

    elif line == "SVC_RADIO":
        svc_restart_radio()

    elif line == "SVC_WIFI":
        svc_restart_wifi()

    elif line == "SVC_SHUTDOWN":
        svc_power("poweroff")

    elif line == "SVC_REBOOT":
        svc_power("reboot")
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

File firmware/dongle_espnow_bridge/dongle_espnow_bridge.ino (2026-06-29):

#include <WiFi.h>
#include <esp_now.h>
#include <esp_wifi.h>

#define ESPNOW_CHANNEL 1
#define LED_PIN 8

static const uint8_t BROADCAST[6] = { 0xFF, 0xFF, 0xFF, 0xFF, 0xFF, 0xFF };

static uint8_t remote_mac[6];
static bool    have_remote = false;

static char    out_line[260];     
static size_t  out_len = 0;

static unsigned long led_off_at = 0;

static void led(bool on) { digitalWrite(LED_PIN, on ? LOW : HIGH); }  // active LOW

#if ESP_ARDUINO_VERSION >= ESP_ARDUINO_VERSION_VAL(3, 0, 0)
void onRecv(const esp_now_recv_info_t *info, const uint8_t *data, int len) {
  const uint8_t *src = info->src_addr;
#else
void onRecv(const uint8_t *mac, const uint8_t *data, int len) {
  const uint8_t *src = mac;
#endif
  memcpy(remote_mac, src, 6);
  if (!have_remote) {
    esp_now_peer_info_t peer = {};
    memcpy(peer.peer_addr, remote_mac, 6);
    peer.channel = ESPNOW_CHANNEL;
    peer.encrypt = false;
    esp_now_add_peer(&peer);
    have_remote = true;
  }

  // "HELLO" is just the remote announcing itself so we learn its MAC and can
  // unicast status back -- don't forward it to the Pi as a command.
  bool is_hello = (len == 5 && memcmp(data, "HELLO", 5) == 0);
  if (!is_hello) {
    Serial.write(data, len);
    if (len == 0 || data[len - 1] != '\n') Serial.write('\n');
  }

  led(true);
  led_off_at = millis() + 30;     // brief activity flash
}

void setup() {
  pinMode(LED_PIN, OUTPUT);
  led(false);
  Serial.begin(115200);

  WiFi.mode(WIFI_STA);
  WiFi.disconnect();
  esp_wifi_set_channel(ESPNOW_CHANNEL, WIFI_SECOND_CHAN_NONE);
  esp_wifi_set_ps(WIFI_PS_NONE);    // no modem sleep

  if (esp_now_init() != ESP_OK) {
    while (true) { led(true); delay(100); led(false); delay(100); }  // SOS blink
  }
  esp_now_register_recv_cb(onRecv);

  esp_now_peer_info_t bpeer = {};
  memcpy(bpeer.peer_addr, BROADCAST, 6);
  bpeer.channel = ESPNOW_CHANNEL;
  bpeer.encrypt = false;
  esp_now_add_peer(&bpeer);
}

void loop() {
  while (Serial.available()) {
    char c = Serial.read();
    if (c == '\n' || c == '\r') {
      if (out_len > 0) {
        const uint8_t *dst = have_remote ? remote_mac : BROADCAST;
        esp_now_send(dst, (const uint8_t *)out_line, out_len);
      }
      out_len = 0;
    } else if (out_len < sizeof(out_line) - 1) {
      out_line[out_len++] = c;
    }
  }

  if (led_off_at && millis() > led_off_at) { led(false); led_off_at = 0; }
}

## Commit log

2026-06-25 main commit w basically everything
    [TopAndBottomCaseMusicPi.3mf, TopCaseMusicPi.3mf]
2026-06-29 Updated README, removed unnecessary comments and improved code clarity in dongle_espnow_bridge.ino.
    Added new radio stations in music_controller.py, Enhanced button handling and UI features in remote_espnow.ino.
2026-06-29 Added media, updated readme to be moer specific and to include media, refactored firmware folder to have receiver, remote, and raspi folders, and added kicad files
    [TopCaseMusicPi.3mf, remoteMusicPi.kicad_pcb, remoteMusicPi.kicad_sch]
2026-06-29 fixed CRITICAL error with how I refactored code, also added OLED timeout after 15 seconds of inactivity, with a switch in the service menu
    [remote_espnow.ino]
2026-06-29 Add GitHub Actions workflow for Arduino and python compilation
2026-06-29 Update arduino-compile.yml 2
2026-06-30 Added hardware.md and fixed version number in remote_espnow
    [remote_espnow.ino]
2026-06-30 reformat 3d files, include images of PCB and SCH inside Kicad folder, add CODEOWNERS file
    [BottomCase.step, BottomCase.stl, TopAndBottomCaseMusicPi.3mf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]
2026-06-30 Created bill of materials
    [BOM.csv]
2026-06-30 fixed error with version number
    [remote_espnow.ino]
